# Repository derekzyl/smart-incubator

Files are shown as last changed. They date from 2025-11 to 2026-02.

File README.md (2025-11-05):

# Smart Incubator with Automatic Egg Turning

A precision-controlled egg incubator system with real-time monitoring, automatic egg turning, and cloud-connected analytics.

## System Overview

This project consists of three main components:

1. **ESP32 Firmware** (`incubator-firmware/`) - Embedded controller with sensor reading, PID temperature control, and egg turning
2. **FastAPI Backend** (`backend/`) - REST API and WebSocket server for data logging and analytics
3. **Flutter Mobile App** (`incubator_app/`) - Cross-platform mobile app for monitoring and control

## Features

- **Dual-Sensor Temperature Monitoring**: DS18B20 and SHT31 sensors for redundancy
- **PID Temperature Control**: Precise temperature regulation with automatic heater control
- **Automated Humidity Control**: Ultrasonic humidifier with automatic on/off
- **Automatic Egg Turning**: Stepper motor-based turning every 2-4 hours
- **Real-Time Monitoring**: WebSocket-based live updates to mobile app
- **Historical Analytics**: 7-day charts and hatch success prediction
- **Alert System**: Critical temperature/humidity alerts with notifications
- **RTC-Based Scheduling**: Turning schedule survives power outages

## Hardware Requirements

See the detailed component list in the project specification. Key components:

- ESP32-WROOM-32D microcontroller
- DS18B20 temperature sensors (×2)
- SHT31 temperature/humidity sensor
- DS3231 RTC module
- NEMA 17 stepper motor with DRV8825 driver
- SSR-25DA solid state relay for heater control
- 12V DC fans and ultrasonic mist maker
- Ceramic PTC heater (12V 100W)

## Quick Start

### 1. Backend Setup

```bash
cd backend
pip install -r requirements.txt
cp .env.example .env
# Edit .env with your configuration
python main.py
```

Backend will run on `http://localhost:8000`

### 2. Flutter App Setup

```bash
cd incubator_app
flutter pub get
# Update API endpoints in services
flutter run
```

### 3. ESP32 Firmware Setup

```bash
cd incubator-firmware
# Install PlatformIO
# Open project in PlatformIO
# Update WiFi and API settings in src/main.cpp
pio run -t upload
```

## Project Structure

```
incubator/
├── backend/                 # FastAPI backend
│   ├── main.py             # Main application
│   ├── requirements.txt    # Python dependencies
│   └── README.md
├── incubator_app/          # Flutter mobile app
│   ├── lib/
│   │   ├── main.dart
│   │   ├── models/
│   │   ├── services/
│   │   ├── screens/
│   │   └── widgets/
│   ├── pubspec.yaml
│   └── README.md
├── incubator-firmware/     # ESP32 firmware
│   ├── src/
│   │   └── main.cpp       # Main firmware code
│   ├── platformio.ini     # PlatformIO configuration
│   └── README.md
└── README.md              # This file
```

## Configuration

### Backend
- Update `DATABASE_URL` in `.env` for database connection
- Configure `REDIS_URL` for WebSocket support (optional)
- Set `TWILIO_*` credentials for SMS alerts (optional)

### Flutter App
- Update `baseUrl` in `lib/services/incubator_service.dart`
- Update `wsBaseUrl` in `lib/services/websocket_service.dart`
- Configure incubator ID (currently uses demo ID)

### ESP32 Firmware
- Set WiFi SSID and password
- Configure API endpoint URL
- Set target temperature and humidity
- Adjust PID parameters for your heater setup
- Configure stepper motor steps based on your gearing

## API Documentation

Once the backend is running, visit:
- Swagger UI: `http://localhost:8000/docs`
- ReDoc: `http://localhost:8000/redoc`

## Safety Features

- Thermal fuse (77°C) for overheat protection
- Dual temperature sensors for redundancy
- Sensor disagreement detection (>2°C difference triggers alert)
- Critical temperature alarms (<35°C or >40°C)
- Emergency stop capability via mobile app

## Development

### Testing Backend
```bash
cd backend
pytest  # If tests are added
```

### Testing Flutter App
```bash
cd incubator_app
flutter test
```

### Monitoring ESP32
Connect via serial monitor at 115200 baud to view sensor readings and system status.

## License

This project is provided as-is for educational and personal use.

## Support

For issues or questions, please refer to the individual component README files or create an issue in the repository.

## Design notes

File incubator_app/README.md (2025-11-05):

# Smart Incubator Mobile App

Flutter mobile application for monitoring and controlling the Smart Incubator system.

## Features

- **Live Dashboard**: Real-time temperature and humidity gauges
- **Historical Charts**: 7-day temperature and humidity graphs
- **Analytics**: Hatch success prediction and performance metrics
- **Settings**: Configure target temperature, humidity, and turn intervals
- **WebSocket Updates**: Real-time sensor data without polling
- **Alerts**: Visual notifications for critical conditions

## Setup

1. Install Flutter SDK (3.9.2 or later)

2. Install dependencies:
```bash
flutter pub get
```

3. Update API endpoint in `lib/services/incubator_service.dart`:
```dart
static const String baseUrl = 'http://YOUR_SERVER_IP:8000/api/v1';
```

4. Update WebSocket URL in `lib/services/websocket_service.dart`:
```dart
static const String wsBaseUrl = 'ws://YOUR_SERVER_IP:8000/ws/live';
```

5. Run the app:
```bash
flutter run
```

## Building

### Android
```bash
flutter build apk --release
```

### iOS
```bash
flutter build ios --release
```

## Project Structure

```
lib/
├── main.dart              # App entry point
├── models/               # Data models
│   ├── sensor_data.dart
│   ├── incubator_config.dart
│   └── alert.dart
├── services/            # API and WebSocket services
│   ├── incubator_service.dart
│   └── websocket_service.dart
├── screens/             # App screens
│   ├── dashboard_screen.dart
│   ├── history_screen.dart
│   ├── analytics_screen.dart
│   └── settings_screen.dart
└── widgets/             # Reusable widgets
    ├── temp_gauge.dart
    └── humidity_gauge.dart
```

## Configuration

The app uses a default incubator ID for demo purposes. In production, implement user authentication and incubator selection.

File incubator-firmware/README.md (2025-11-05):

# Smart Incubator Firmware

ESP32 firmware for the Smart Incubator system.

## Configuration

Before uploading, update these values in `src/main.cpp`:

1. **WiFi credentials:**
   ```cpp
   const char* ssid = "YOUR_WIFI_SSID";
   const char* password = "YOUR_WIFI_PASSWORD";
   ```

2. **API endpoint:**
   ```cpp
   const char* apiUrl = "http://YOUR_SERVER_IP:8000/api/v1/sensors/upload";
   const char* incubatorId = "your-incubator-id";
   ```

3. **Control parameters:**
   ```cpp
   double targetTemp = 37.5;        // Target temperature (°C)
   double targetHumidity = 55.0;     // Target humidity (%)
   int turnIntervalHours = 4;        // Hours between turns
   int turnAngle = 45;               // Degrees to turn eggs
   ```

4. **Stepper motor steps:**
   Adjust `stepsPerTurn` based on your motor and gearing:
   ```cpp
   const int stepsPerTurn = 200;  // Adjust for your setup
   ```

## PID Tuning

The PID controller uses these default values:
- Kp = 2.0
- Ki = 5.0
- Kd = 1.0

Tune these values based on your heater response time and incubator thermal mass.

## Building and Uploading

1. Install PlatformIO
2. Open this project in PlatformIO
3. Update configuration in `src/main.cpp`
4. Build and upload:
   ```bash
   pio run -t upload
   ```

## Pin Connections

- **DS18B20 sensors:** GPIO4 (1-wire bus)
- **SHT31:** GPIO21 (SDA), GPIO22 (SCL)
- **RTC DS3231:** GPIO21 (SDA), GPIO22 (SCL) - shared I2C bus
- **Heater SSR:** GPIO25
- **Fan PWM:** GPIO26
- **Humidifier Relay:** GPIO27
- **Buzzer:** GPIO14
- **Stepper:** GPIO32 (STEP), GPIO33 (DIR), GPIO13 (ENABLE)
- **LEDs:** GPIO2 (heater), GPIO12 (humidifier), GPIO15 (status)

## Testing

1. Monitor serial output at 115200 baud
2. Check sensor readings appear every 5 seconds
3. Verify data uploads to API every 30 seconds
4. Test egg turning by adjusting `turnIntervalHours` to 1 minute for testing

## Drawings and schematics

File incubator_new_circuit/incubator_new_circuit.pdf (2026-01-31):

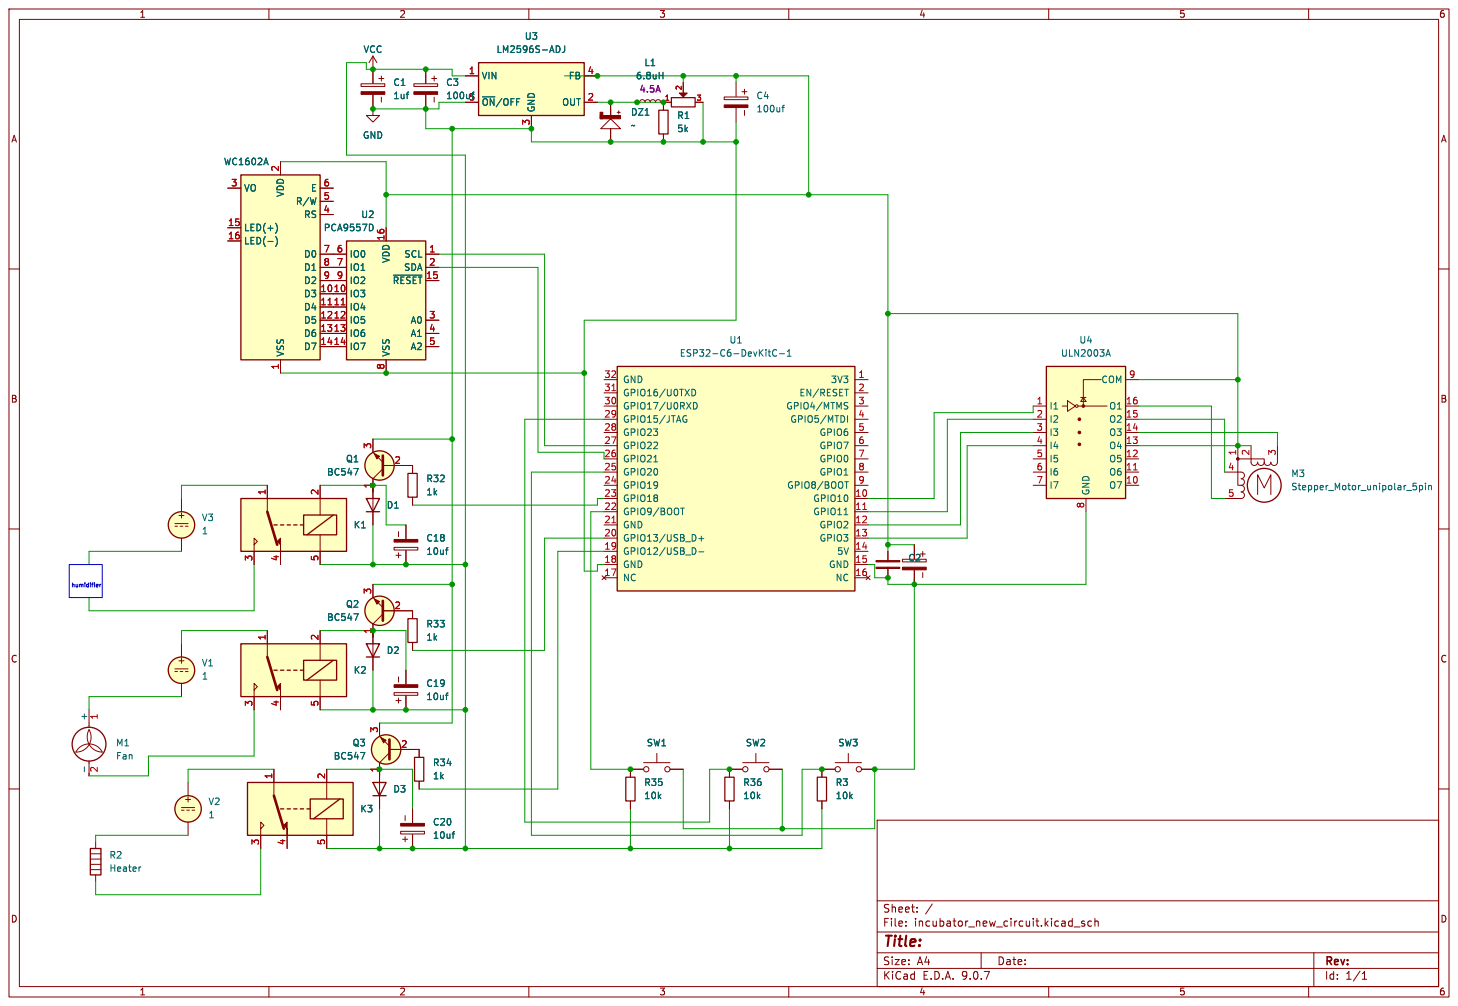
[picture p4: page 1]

SCL 1 SDA 2 ~{RESET} 15 A0 3 A1 4 A2 5 VDD 16 VSS 8

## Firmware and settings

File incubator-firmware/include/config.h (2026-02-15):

#ifndef CONFIG_H
#define CONFIG_H

#include <Arduino.h>

// --- Pin Definitions ---

// Relays
#define PIN_RELAY_FAN       13
#define PIN_RELAY_HEATER    33
#define PIN_RELAY_HUMID     23

// Relay Logic (BC547 NPN Switch - Active HIGH)
#define RELAY_ACTIVE_LOW    false 
#define RELAY_ON            (RELAY_ACTIVE_LOW ? LOW : HIGH)
#define RELAY_OFF           (RELAY_ACTIVE_LOW ? HIGH : LOW)

// Servo Motor (Egg Turner)
#define PIN_SERVO           18
#define DEFAULT_SERVO_RETRACT 0
#define DEFAULT_SERVO_EXTEND  170 // Increased from 90 per user request
#define DEFAULT_TURN_INTERVAL 240 // Minutes (4 hours for chicken eggs)


// Buttons
#define PIN_BUTTON_MODE     4
#define PIN_BUTTON_SET      35 // Note: GPIO 35 is Input Only, needs EXTERNAL 10k PULL-UP resistor

// Sensors
#define PIN_DHT             32

// I2C (LCD + RTC)
#define PIN_I2C_SDA         21
#define PIN_I2C_SCL         22

// --- WiFi Configuration ---
#define WIFI_SSID           "cybergenii"
#define WIFI_PASS           "12341234"
#define AP_SSID             "SmartIncubator_AP"
#define AP_PASS             "incubator123"

// --- System Configuration ---

// Telegram Configuration
#define TELEGRAM_BOT_TOKEN  "8579627355:AAGkoki40J8X4P8jL6oAwselL_SKbRfMh8A" // Get from @BotFather
#define TELEGRAM_CHAT_ID    "2135710999"   // Get from @IDBot

// Serial Communication
#define SERIAL_BAUD_RATE    115200

// Sensor Settings
#define DHT_TYPE            DHT22



// Default Thresholds for egg hatching (chicken eggs - can be overridden by app/NVS)
#define DEFAULT_TEMP_MIN    37.0
#define DEFAULT_TEMP_MAX    38.0
#define DEFAULT_HUMID_MIN   50.0
#define DEFAULT_HUMID_MAX   65.0
#define DEFAULT_HYSTERESIS  0.5

#endif // CONFIG_H

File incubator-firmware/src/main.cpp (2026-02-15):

#include <Arduino.h>
#include "config.h"
#include "sensors.h"
#include "relays.h"
#include "servo_control.h"
#include "display.h"
#include "buttons.h"
#include "storage.h"
#include "automation.h"
#include "wifi_manager.h"
#include "webserver.h"
#include "scheduler.h"
#include "notifications.h"
#include "logger.h"

// --- Global Objects ---
EnvironmentSensor envSensor;
RelayController relays;
ServoController servo;
DisplayController display;

ButtonHandler buttons;
SettingsManager settingsManager;
Scheduler scheduler(envSensor, relays, settingsManager);
NotificationManager notifications;
Logger logger;
AutomationEngine automation(envSensor, relays, servo, settingsManager, scheduler, notifications);
WifiManager wifiManager;
WebServerManager webServer(envSensor, relays, servo, settingsManager, automation, scheduler, logger);


// System Mode managed by AutomationEngine

void setup() {
    Serial.begin(SERIAL_BAUD_RATE);
    Serial.println("Starting ESP32 Environmental Control System...");

    // Initialize Modules
    settingsManager.begin();
    envSensor.begin();
    scheduler.begin(); // Load schedules
    notifications.begin();
    logger.begin();
    relays.begin();
    servo.begin();
    display.begin();
    buttons.begin();
    
    // Connect to WiFi
    wifiManager.begin();
    
    // Start Web Server
    webServer.begin();

    Serial.println("Initialization Complete.");
}

void loop() {
    // 0. Update WiFi & WebServer
    wifiManager.update();
    webServer.update();

    // 1. Update Sensors
    envSensor.update();

    // Notify IP on Connection
    static bool ipSent = false;
    if (wifiManager.isConnected()) {
        if (!ipSent) {
            String ip = wifiManager.getIP();
            float temp = envSensor.getTemperature();
            String msg = "✅ *Incubator Online*\n\n";
            msg += "IP Address: `" + ip + "`\n";
            msg += "Temp: " + String(temp, 1) + "°C";
            notifications.sendMessage(msg);
            ipSent = true;
        }
    } else {
        ipSent = false;
    }

    // 2. Handle Buttons
    int currentMode = automation.getMode();
    if (buttons.isModeButtonPressed()) {
        if (currentMode == 0) currentMode = 1; // Auto -> Manual
        else if (currentMode == 1) currentMode = 2; // Manual -> Schedule
        else currentMode = 0; // Schedule -> Auto
        
        automation.setMode(currentMode); 
        
        Serial.print("Mode changed to: ");
        Serial.println(currentMode);
    }
    
    // (Button 2 logic: Toggle Fan manually if in Manual Mode)
    if (buttons.isSetButtonPressed()) {
        Serial.println("Set button pressed");
        Serial.printf("Current mode: %d\n", automation.getMode());
        if (automation.getMode() == 1) { // Manual
            bool state = relays.getFanState();
            relays.setFan(!state);
            Serial.printf("Manual: Fan toggled to %s\n", !state ? "ON" : "OFF");
        } else {
            Serial.println("Not in manual mode - fan toggle ignored");
        }
    }

    // 3. Update Stepper (Not needed for Servo)
    // servo.update(); 


    // 4. Update Display (Rate Limited to 500ms)
    static unsigned long lastDisplayUpdate = 0;
    if (millis() - lastDisplayUpdate > 500) {
        lastDisplayUpdate = millis();
        
        String modeStr;
        int m = automation.getMode();
        if (m == 0) modeStr = "AUTO";
        else if (m == 1) modeStr = "MAN "; 
        else modeStr = "SCHD";

        display.update(
            envSensor.getTemperature(),
            envSensor.getHumidity(),
            envSensor.getDateTime(),
            relays.getFanState(),
            relays.getHeaterState(),
            relays.getHumidifierState(),
            modeStr,
            wifiManager.getIP()
        );
    }

    // 5. Automation Logic
    automation.update();

    // 6. Data Logging (Every 5 minutes)
    static unsigned long lastLogTime = 0;
    if (millis() - lastLogTime > 300000) { // 300000 ms = 5 mins
        lastLogTime = millis();
        // Only log if time is valid (year > 2000)
        String dt = envSensor.getDateTime();
        if (dt.indexOf("2000") == -1) { // Simple check, better would be year check
             logger.logData(envSensor.getTemperature(), envSensor.getHumidity(), dt);
             Serial.println("Data logged.");
        } else {
             // Fallback: Log anyway for debugging/demo purposes even if time is wrong
             logger.logData(envSensor.getTemperature(), envSensor.getHumidity(), dt);
             Serial.println("Data logged (Time not synced).");
        }
    }
    
    // Heartbeat (Every 1s)
    static unsigned long lastHeartbeat = 0;
    if (millis() - lastHeartbeat > 1000) {
        lastHeartbeat = millis();
        Serial.println("Loop running...");
    }

    // Comprehensive Debug Status (Every 5s)
    static unsigned long lastDebug = 0;
    if (millis() - lastDebug > 5000) {
        lastDebug = millis();
        Serial.println("=== SYSTEM STATUS ===");
        float t = envSensor.getTemperature();
        float h = envSensor.getHumidity();
        Serial.printf("Mode: %d | Temp: %.1f | Humid: %.1f\n", automation.getMode(), t, h);
        if (isnan(t) || isnan(h)) Serial.println("WARNING: Sensor reading is NAN");
        
        Serial.println("====================");
        Serial.printf("Heater: %s | Fan: %s | Humidifier: %s\n",
            relays.getHeaterState() ? "ON" : "OFF",
            relays.getFanState() ? "ON" : "OFF",
            relays.getHumidifierState() ? "ON" : "OFF");
        Serial.println("====================");
    }
}

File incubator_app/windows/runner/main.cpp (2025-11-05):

#include <flutter/dart_project.h>
#include <flutter/flutter_view_controller.h>
#include <windows.h>

#include "flutter_window.h"
#include "utils.h"

int APIENTRY wWinMain(_In_ HINSTANCE instance, _In_opt_ HINSTANCE prev,
                      _In_ wchar_t *command_line, _In_ int show_command) {
  // Attach to console when present (e.g., 'flutter run') or create a
  // new console when running with a debugger.
  if (!::AttachConsole(ATTACH_PARENT_PROCESS) && ::IsDebuggerPresent()) {
    CreateAndAttachConsole();
  }

  // Initialize COM, so that it is available for use in the library and/or
  // plugins.
  ::CoInitializeEx(nullptr, COINIT_APARTMENTTHREADED);

  flutter::DartProject project(L"data");

  std::vector<std::string> command_line_arguments =
      GetCommandLineArguments();

  project.set_dart_entrypoint_arguments(std::move(command_line_arguments));

  FlutterWindow window(project);
  Win32Window::Point origin(10, 10);
  Win32Window::Size size(1280, 720);
  if (!window.Create(L"incubator_app", origin, size)) {
    return EXIT_FAILURE;
  }
  window.SetQuitOnClose(true);

  ::MSG msg;
  while (::GetMessage(&msg, nullptr, 0, 0)) {
    ::TranslateMessage(&msg);
    ::DispatchMessage(&msg);
  }

  ::CoUninitialize();
  return EXIT_SUCCESS;
}

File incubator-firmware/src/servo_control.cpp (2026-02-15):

#include "servo_control.h"

ServoController::ServoController() : _currentAngle(0), _servoPin(PIN_SERVO) {
}

void ServoController::begin() {
    // Allow allocation of all timers
    ESP32PWM::allocateTimer(0);
    ESP32PWM::allocateTimer(1);
    ESP32PWM::allocateTimer(2);
    ESP32PWM::allocateTimer(3);
    
    myservo.setPeriodHertz(50); // Standard 50hz servo
    myservo.attach(_servoPin, 500, 2400); // Standard min/max pulse width
    
    // Initial position
    moveToAngle(DEFAULT_SERVO_RETRACT);
}

void ServoController::moveToAngle(int angle) {
    // Constrain angle
    if (angle < 0) angle = 0;
    if (angle > 180) angle = 180;
    
    myservo.write(angle);
    _currentAngle = angle;
}

int ServoController::getCurrentAngle() {
    return _currentAngle;
}

void ServoController::turnEggs(bool extend, int extendAngle, int retractAngle) {
    if (extend) {
        moveToAngle(extendAngle);
    } else {
        moveToAngle(retractAngle);
    }
}

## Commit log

2025-11-05 Initial commit with project setup and basic structure established.
    [incubator-pcb-design.kicad_pcb, incubator-pcb-design.kicad_sch]
2025-12-12 Populate KiCad PCB project settings; add fp-info-cache and backup
    - Expand design defaults, DRC rules, teardrop & tuning parameters in incubator-pcb-design.kicad_pro
    - Initialize net inspector panel columns and set sorting column in incubator-pcb-design.kicad_prl
    - Add fp-info-cache placeholder file
    - Add incubator-pcb-design backup archive
2026-01-28 refactor: Migrate KiCad project from `incubator-pcb-design` to `incubator_new_circuit`.
    [incubator-pcb-design.kicad_sch, incubator_new_circuit.kicad_pcb, incubator_new_circuit.kicad_sch]
2026-01-28 chore: Remove unused schematic symbols and associated generated files from the KiCad project.
    [incubator_new_circuit.kicad_sch]
2026-01-31 feat: Add stepper motor and ULN2003A symbols to the KiCad schematic.
    [incubator_new_circuit.kicad_sch]
2026-02-14 refactor: replace stepper motor control with servo motor control for egg turning
    [config.h, main.cpp, servo_control.cpp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]
2026-02-15 feat: Enhance automation engine with servo control for egg turning and update configuration management
2026-02-19 made circuit design changes
    [incubator-circuitry.kicad_pcb, incubator-circuitry.kicad_sch]
